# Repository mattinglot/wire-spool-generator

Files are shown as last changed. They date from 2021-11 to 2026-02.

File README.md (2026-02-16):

# Wire Spool Generator
[OpenSCAD based wire spool generator](https://www.printables.com/model/87228-electrical-wire-spools-with-customizable-generator/) that produces strong 3D printable spools suitable for winding electrical wire and similar material.

This is based on the original by [Gladius](https://www.prusaprinters.org/prints/18981-customizeable-wire-spools) with some key improvements:

* Stronger design because both rims have cores that mate with each other. The original had the core mating with a small indent in the rim. I found this approach tended to break at the seam even with super glue.
* Enabling wire holes enables them in both rims instead of just the one.
* Tolerance is set in mm instead of %.

## Sample Parameters

### 80mm Spool
  ```
  tolerance=0.1;
  thicknessOfRim=2;
  diameterOfRim=80.0;
  heightOfSpool=40.0;
  diameterOfCore=25.0;
  diameterOfHoleInRim=20.0;
  coreWallThickness=1.2;
  wireHoles=true;
  diameterOfWireHoles=3.0;
  $fn=100;
  ```

## More Info and Makes
https://www.printables.com/model/87228-electrical-wire-spools-with-customizable-generator/

## License
https://creativecommons.org/licenses/by/4.0/

Remixed from ["Customizeable wire Spools"](https://www.prusaprinters.org/prints/18981-customizeable-wire-spools)

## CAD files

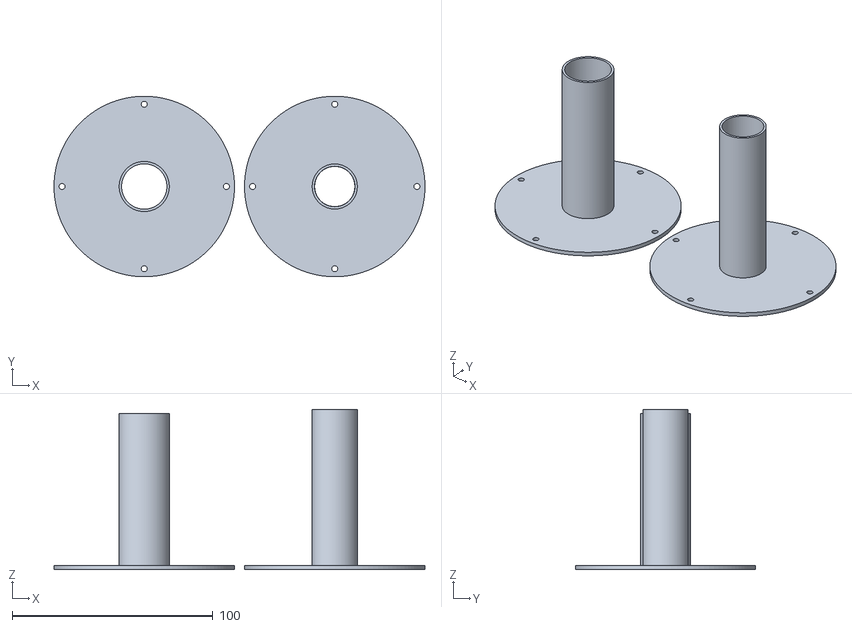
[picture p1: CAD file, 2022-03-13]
STL Samples/spool-generator 90mm diameter 76mm height 20mm core.stl
185.0 x 90.0 x 80.0

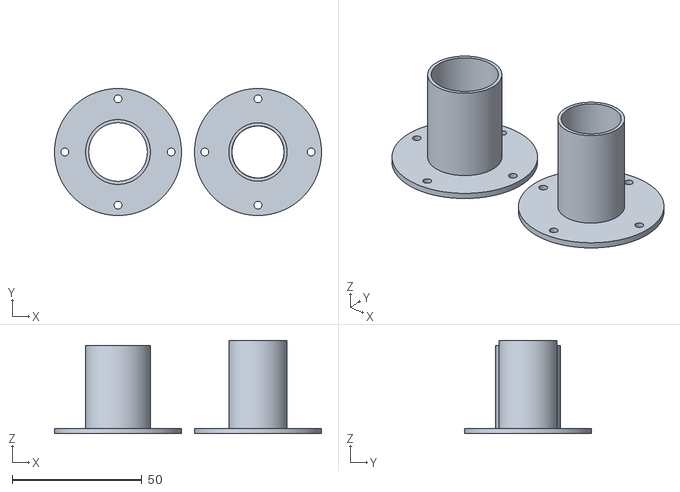
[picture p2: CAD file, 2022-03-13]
STL Samples/spool-generator 49mm.stl
103.0 x 49.0 x 36.0

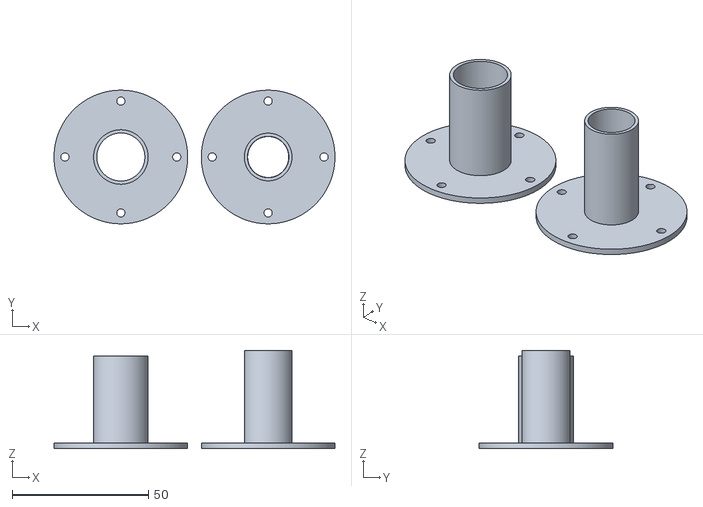
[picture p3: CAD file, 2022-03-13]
STL Samples/spool-generator 49mm Skinny Core.stl
103.0 x 49.0 x 36.0

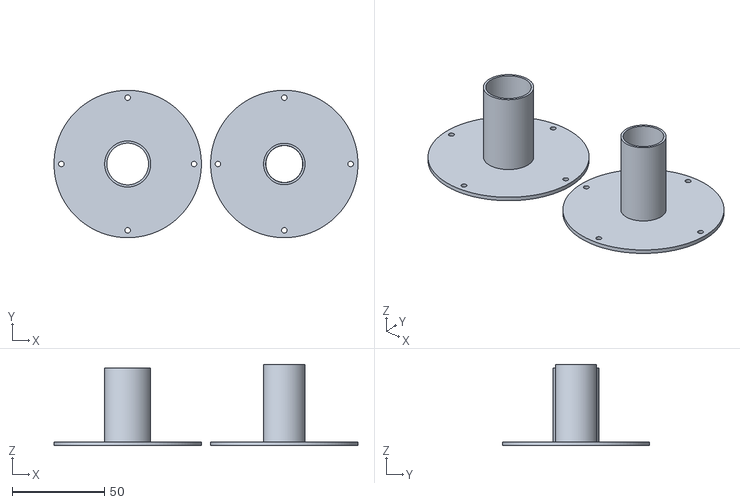
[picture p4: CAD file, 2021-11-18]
STL Samples/spool-generator 80mm.stl
165.0 x 80.0 x 44.0

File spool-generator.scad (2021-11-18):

// Customizable Wire Spools (with sturdier spool)
// Remixed by Matt Inglot from original by Gladius (source:  https://www.prusaprinters.org/prints/18981-customizeable-wire-spools)

// Tolerance in mm between the two cores. Use 0 to not add any spacing between the two cores. If that's too tight, try a small number like 0.2
tolerance=0.1;

// The thickness of each rim.
thicknessOfRim=2;

// The diameter of each rim.
diameterOfRim=80.0;

// The height of the spool's core.
heightOfSpool=40.0;

// The outer diameter of the core. 
diameterOfCore=25.0;

// The diameter of the hole to place in the core. Make sure this fits your intended mounting solution.
diameterOfHoleInRim=20.0;

// How thick the wall of each core is.
coreWallThickness=1.2;

outerCoreWall=(diameterOfCore-2*coreWallThickness);
wireHoles=true;
diameterOfWireHoles=3.0;
//Set facettes
$fn=100;

diameterOfInnerCore=outerCoreWall - tolerance;
innerCoreWall=(diameterOfCore-4*coreWallThickness);
translateRim=diameterOfRim+5;



//create Rim 1 and hole in Rim along with holes for wires
difference(){
    //Rim
    cylinder(thicknessOfRim,d=diameterOfRim);
    //Hole in Rim
    cylinder(thicknessOfRim+(thicknessOfRim-1),d=outerCoreWall);
    //Holes for wires
     if(wireHoles){for(i=[0:90:270]){
           rotate([0,0,i])translate([((diameterOfRim/2)-diameterOfWireHoles-1),0,0])cylinder(thicknessOfRim,d=diameterOfWireHoles); 
        }
    }
}
//create Rim 2 and hole in Rim 
difference(){
    
    //Rim
    translate([translateRim,0,0])    
        //Rim
    cylinder(thicknessOfRim,d=diameterOfRim);
    
    translate([translateRim,0,0])
    //Hole in Rim
    cylinder(thicknessOfRim+(thicknessOfRim-1),d=diameterOfHoleInRim);
    
    
    translate([translateRim,0,0])
    
    
    
    //Holes for wires
    if(wireHoles){for(i=[0:90:270]){
           rotate([0,0,i])translate([((diameterOfRim/2)-diameterOfWireHoles-1),0,0])cylinder(thicknessOfRim,d=diameterOfWireHoles); 
        }
    }
        

}
//create core and add hole to it
difference(){
    //Core
    translate([0,0,thicknessOfRim])cylinder(heightOfSpool,d=diameterOfCore);
    //Hole in Core
    translate([0,0,thicknessOfRim])cylinder(heightOfSpool,d=  outerCoreWall);
    
}


//create core 2 and add hole to it
difference(){
    //Core
    translate([translateRim,0,thicknessOfRim])
    cylinder(heightOfSpool+thicknessOfRim,d=diameterOfInnerCore);
    
    //Hole in Core
    translate([translateRim,0,thicknessOfRim])
    cylinder(heightOfSpool+thicknessOfRim,d=  innerCoreWall);            
}

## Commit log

2021-11-18 Commit of first modified version of the spool generator.
    [spool-generator.scad]
2021-11-18 Added sample 80mm spool. This is a convenient size I use for holding 20m lengths of 22 AWG wire.
    [spool-generator 80mm.stl]
2022-03-13 Added more STL samples.
    [spool-generator 49mm Skinny Core.stl, spool-generator 49mm.stl, spool-generator 90mm diameter 76mm height 20mm core.stl]
